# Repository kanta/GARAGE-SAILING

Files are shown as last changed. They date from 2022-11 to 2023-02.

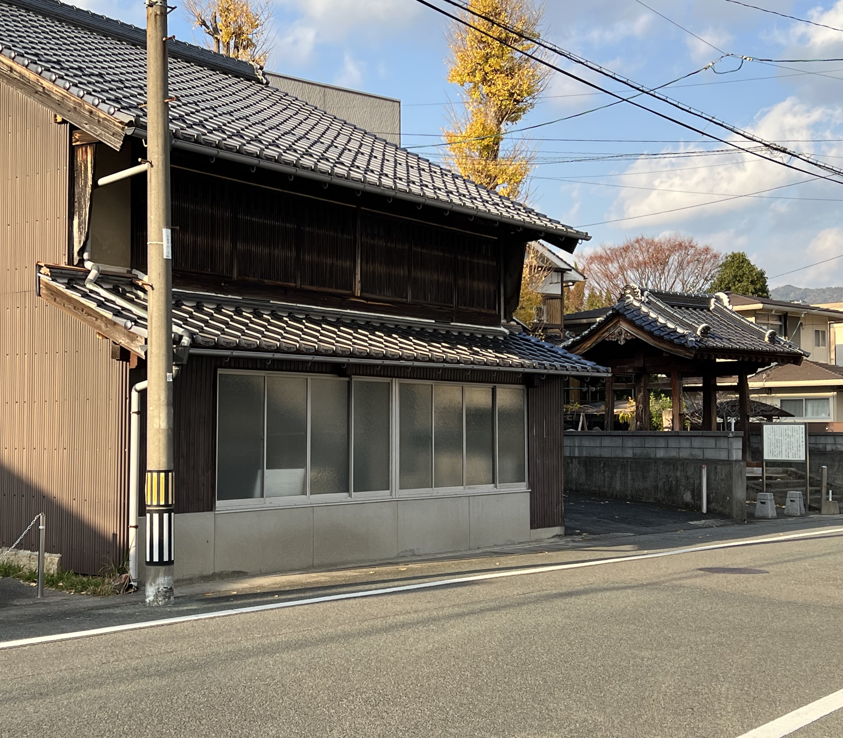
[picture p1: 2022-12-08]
Silk-screen/materials/trimmed_DaF.jpg

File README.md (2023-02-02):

# GARAGE SAILING
- [English](./README_en.md)
- [GARAGE SAILING FMラジオ](https://github.com/kanta/GARAGE-SAILING/tree/main/GarageSailing-FM-radio)

<Strong>梅田哲也 / ジョン・リチャーズ (Dirty Electronics) / ティム・ショウ / 堀尾寛太 </strong>
<a href="https://github.com/kanta/GARAGE-SAILING/blob/main/GarageSailing_Flyer.pdf">garage_sailing_flyer</a>

今冬、サウンド・アーティストのジョン・リチャーズ、ティム・ショウが来日します。2人はそれぞれ楽器や道具をDIYで製作し、UKを拠点に国際的に活躍しています。

Do a Front はもともと二人と交流がある日本のアーティスト・梅田哲也（大阪）と堀尾寛太（東京）を同時に招聘し、4人の滞在制作の成果公演として、日没のマジックアワーにガレージセールとセーリング（航海）をモチーフにした展覧会を開催します。

場内ではアーティストたちがそれぞれの作品テーマに基づいたショップを一時的にオープンし、観客はFMラジオをつかって、アーティストたちが発信する音を受信しながら会場内を移動していきます。ショップで制作した作品はその場で購入することもできます。

国際的に活躍する4人のワールドプレミアとなる新作公演にご期待ください！

## 日時
2022年12月10日（土）<br />
15:00 開場<br />
16:00 展覧会スタート、日没まで

2022年12月11日（日）<br />
10:00 ワークショップ＆製作物展示、日没まで

## 会場
[Do a front](https://www.doafront.org/about/index.html)<br />
山口県山口市堂の前町1-9

入場無料<br />
暖かいお飲み物の販売あり

- ヘッドホンおよび、イヤホンで聞けるFMラジオをご持参ください。
- お持ちでない方には会場で貸し出ししますが、数に限りがございます（滞在制作した自作ラジオを購入することもできます）。
- 会場は寒いので暖かくしてお越しください。

主催　Do a front

## 出演者
### 梅田哲也
Umeda

建物の構造や周囲の環境から着想を得て、その場でしか成立しえない現象としての時間を演出する。これまで美術館や博物館での展覧会のほかに、劇場のパフォーマンス公演や、普段行き慣れない場所へ観客を招待するツアー型の作品を発表。近年の個展・公演には「梅田哲也 イン 別府『Ｏ滞』」（別府、2020-2021年）、「うたの起源」（福岡市美術館、福岡、2019-2020年）、「プレイタイム」（シアターコクーン、2020年）などがある。<br />
https://siranami.com/

### ジョン・リチャーズ (Dirty Electronics)
Richards

ジョン・リチャーズは90年代から音楽や舞台芸術の分野で活動するアーティスト。過去数回にわたって来日し、勅使河原三郎やメルツバウら他のアーティストたちとのコラボレーションを行ってきた。近年は大人数による電子音楽とDIY電子工作のパフォーマンスに関心を持ち、批評的な制作に焦点をあてた「ダーティー・エレクトロニクス」という概念を探求し、ワークショップ・インスタレーションやパフォーマンス・インスタレーション、執筆活動など、さまざまな方法で即興的な実線を行っている。<br />
https://www.dirtyelectronics.org/

### ティム・ショウ
Shaw

音、光、コミュニケーション・メディアを扱うアーティスト。パフォーマンス、インスタレーション、サウンドウォークなどの形で作品を発表している。フィールドレコーディング、電子工作、ビデオ、モジュラーシンセシス、サウンドオブジェクト、自作ハードウェア、DIYソフトウェアなどを用いた彼の作品、録音、文章は「The Guardian」や「BBC」を中心とした数多くの国際的なメディアで紹介されている。初来日。<br />
https://tim-shaw.net/

### 堀尾寛太
Horio

日用品や自作の装置を使って音や光、磁力、位置などのエネルギーと物理的な動きを結びつけ、その場で自律的に発生する現象を作るライブパフォーマンスやインスタレーション作品を発表している。また、エンジニアとして触覚と振動に基づく電子楽器やインタフェースの開発・製作を行っている。近年の活動・展覧会には、ボアダムズの∈Y∋を中心としたユニット「FINALBY( )」（2021年〜）や、「streaming heritage 2021 autumn」（名古屋市内、2021年）などがある。<br />
https://horiokanta.com/

## クレジット
- 藏田章子：企画
- 尾中俊介 (Calamari inc)：フライヤーデザイン
- アリ・シャリフッディン：ハーブ・薬草茶
- 時里充：映像技術、映像機材協力
- 大脇理智：音響機材・映像機材協力
- 東岳志：音響ケーブル協力

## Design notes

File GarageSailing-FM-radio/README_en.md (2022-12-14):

# GARAGE SAILING FM RADIO
[日本語](README.md)



## How to use
### 1. Power switch
When you turn the switch on, you will see a green light from the round indicator avobe the switch. This will blink once in 2 seconds.
### 2. Earphone jack
A cable of your earphone will work as an anntena as well.

### 3. Volume adjust
You can change the volume with both triangle touch switches.

### 4. Scan switch
When you push the switch, radio will scan FM stations automatically. During scanning, you will see a color from the indicator next to the switch. This colour shows the frequency of the radio. Red means low frequency and purple means high frequency, as visible light spectrum. When the radio turned the station, the scan will be stopped and the indicator will be turned off.

### 5. "Ghost Radio"
This touch switch triggers "Ghost Radio" function, which jump among frequencies random and quick, to hear the sound of ghosts.

### 6. Screws for changing batteries
You can change batteries with removing these 2 screws. This radio uses 2 UM-4 batteries.

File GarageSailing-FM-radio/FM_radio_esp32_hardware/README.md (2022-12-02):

KiCad 6.0 project files for the top and the bottom panel.

FM_radio_esp32_top

BOM list:
https://docs.google.com/spreadsheets/d/1gx5q1M0V2GI4ifzEtNZcrifsvwdLu0RDMLZBMcAdJLQ/edit?usp=sharing

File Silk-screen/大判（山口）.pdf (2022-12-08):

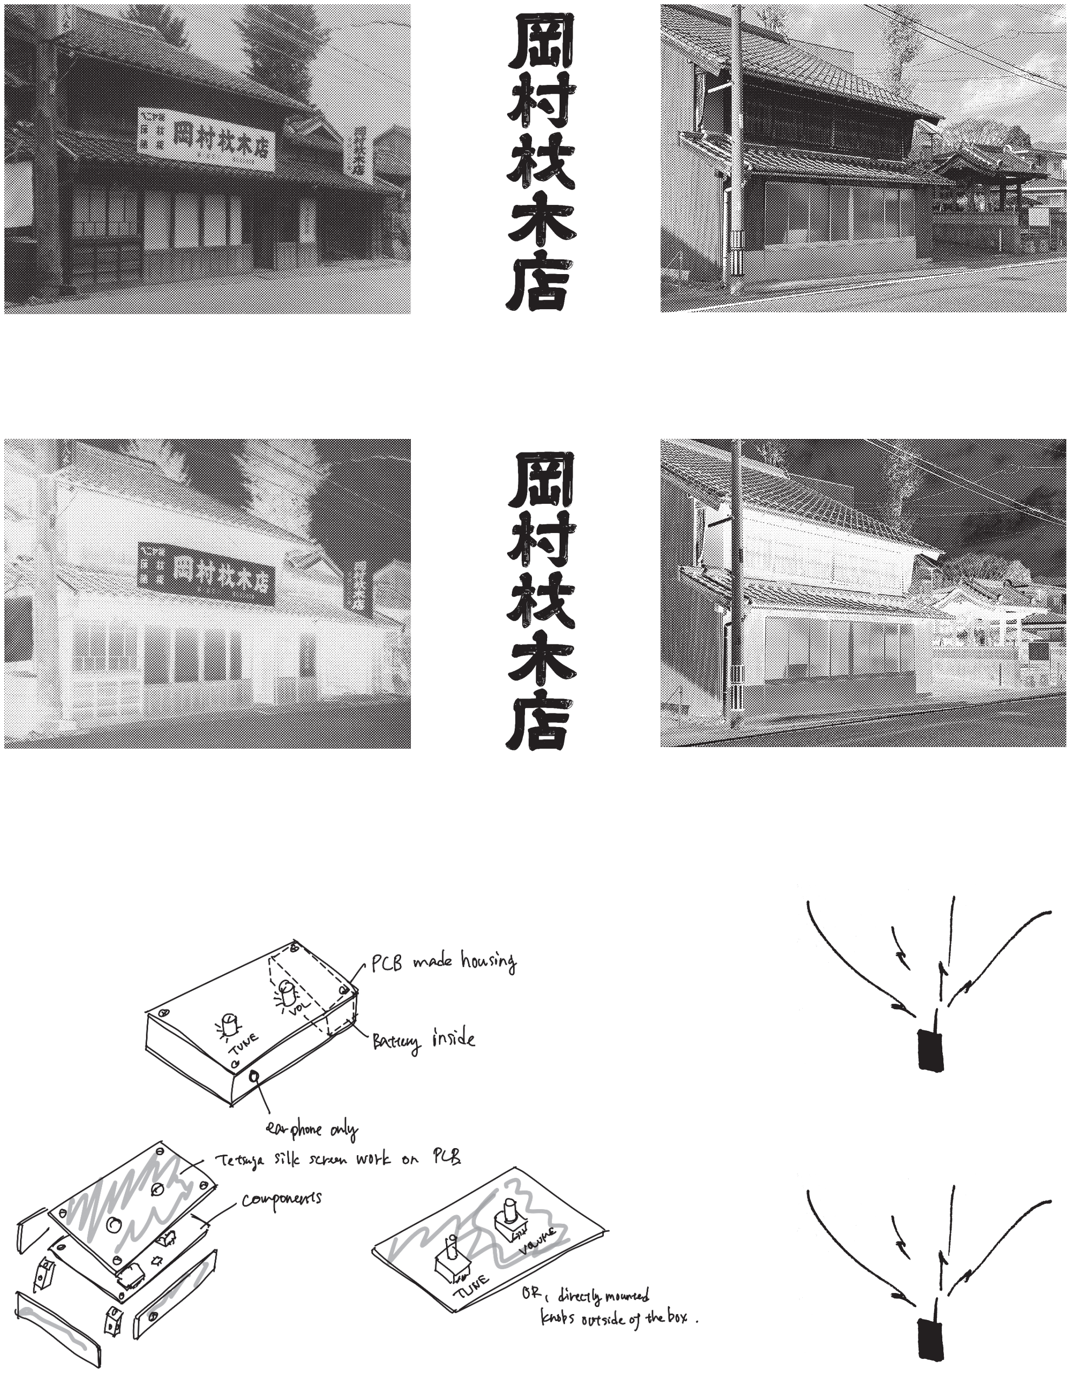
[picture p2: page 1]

１３cm | １３cm
２２cm | ８cm

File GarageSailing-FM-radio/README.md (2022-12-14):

# GARAGE SAILING FM RADIO
[English](README_en.md)



## 使い方
### 1. 電源スイッチ
電源を入れると、スイッチ上の〇部分が緑色に光ります。この緑色は2秒に1回光ります。
### 2. イヤフォンジャック
イヤフォンの線はアンテナを兼ねています。
### 3. 音量調整 
上下の三角がタッチスイッチになっていて、音量を調節できます。
### 4. スキャンスイッチ
このボタン押すと自動的に放送局をスキャンします。スキャン中は5番の位置にあるLEDが点灯し、色で周波数を表しています。光の波長に倣って、低い周波数が赤色、高い周波数が紫色です。チューニングが合うとスキャンが停止し、5番LEDが消灯します。
### 5. "Ghost Radio"
周波数を高速かつランダムにスキャンして霊の声を聴くという"Ghost Radio"の機能です。

### 6. 電池交換時に取り外すねじ
電池は単4電池2本です。音が鳴らなくなったら、この2つのねじを外して電池ボックスを取り出し、電池を交換してください。

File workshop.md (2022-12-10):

# GARAGE SAILING ワークショップ: RADICAL “WOOD” CHIP


## 日時：
2022年12月11日（日）10:30-13:00

## 会場：
Do a front

## 参加費
2500円（材料費含む）

## 定員：
6名まで

## 説明：
Dirty Electronicsのアットホームなワークショップに参加しませんか？<br />
電子部品の材料シリコンチップとウッドチップ、そして釘が出会う元材木店で、自分だけのRadical 'Wood' Chip シンセサイザーを作りましょう。<br />
このワークショップでは、木と釘と電子部品で回路を作って、自分だけのオブジェを作ります。年齢や予備知識、能力を問わずご参加いただけます。工具や材料はこちらでご提供します。<br />

https://github.com/kanta/GARAGE-SAILING
https://dirtyelectronics.org

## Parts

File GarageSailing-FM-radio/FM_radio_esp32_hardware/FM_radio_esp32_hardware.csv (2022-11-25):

Cmp name | Value | Footprint | Ref | Qty | Description
C | 0.1uF | Capacitor_SMD:C_0603_1608Metric | C1, C6 | 2 | Unpolarized capacitor
C | 1u | Capacitor_SMD:C_0603_1608Metric | C2 | 1 | Unpolarized capacitor
C | 10uF | Capacitor_SMD:C_0805_2012Metric | C3, C4 | 2 | Unpolarized capacitor
C | 47uF | Capacitor_SMD:C_1210_3225Metric | C5 | 1 | Unpolarized capacitor
C | 1nF | Capacitor_SMD:C_0603_1608Metric | C7 | 1 | Unpolarized capacitor
LED | LED | FM_radio_esp32:LED_D3.0mm | D1 | 1 | Light emitting diode
LED_RGBK | LED_RGBK | LED_THT:LED_D5.0mm-4_RGB_Wide_Pins | D3 | 1 | RGB LED, red/green/blue/cathode
D_Zener | D_Zener | Diode_SMD:D_SOD-323 | D4 | 1 | Zener diode
MountingHole_Pad | MountingHole_Pad | TestPoint:TestPoint_Keystone_5019_Minature | H1 | 1 | Mounting Hole with connection
MountingHole_Pad | MountingHole_Pad | MountingHole:MountingHole_3.2mm_M3_Pad | H2, H3, H4, H5 | 4 | Mounting Hole with connection
MountingHole | MountingHole | MountingHole:MountingHole_3.2mm_M3 | H6, H7, H8, H9 | 4 | Mounting Hole without connection
MountingHole | MountingHole | FM_radio_esp32:Hole_8mm | H10 | 1 | Mounting Hole without connection
MountingHole | MountingHole | MountingHole:MountingHole_6.5mm | H11 | 1 | Mounting Hole without connection
AudioJack2_Ground_SwitchT | AudioJack2_Ground_SwitchT | FM_radio_esp32:Jack_3.5mm_RS_913-1055 | J1 | 1 | Audio Jack, 2 Poles (Mono / TS), Grounded Sleeve, Switched T Pole (Normalling)
Conn_01x06 | Conn_01x06 | Connector_PinHeader_2.54mm:PinHeader_1x06_P2.54mm_Vertical_SMD_Pin1Left | J2 | 1 | Generic connector, single row, 01x06, script generated (kicad-library-utils/schlib/autogen/connector/)
Conn_02x03_Odd_Even | Conn_02x03_Odd_Even | Connector_PinHeader_2.54mm:PinHeader_2x03_P2.54mm_Vertical_SMD | J3 | 1 | Generic connector, double row, 02x03, odd/even pin numbering scheme (row 1 odd numbers, row 2 even numbers), script generated (kicad-library-utils/schlib/autogen/connector/)
Conn_02x03_Odd_Even | Conn_02x03_Odd_Even | Connector_PinSocket_2.54mm:PinSocket_2x03_P2.54mm_Vertical_SMD | J4 | 1 | Generic connector, double row, 02x03, odd/even pin numbering scheme (row 1 odd numbers, row 2 even numbers), script generated (kicad-library-utils/schlib/autogen/connector/)
R | 10k | Resistor_SMD:R_0603_1608Metric | R1, R2, R3 | 3 | Resistor
R | 1k | Resistor_SMD:R_0603_1608Metric | R4, R8 | 2 | Resistor
R | 330 | Resistor_SMD:R_0603_1608Metric | R6, R7 | 2 | Resistor
SW_Push | SW_Push | Button_Switch_SMD:SW_SPST_SKQG_WithoutStem | SW1 | 1 | Push button switch, generic, two pins
SW_SPDT | SW_SPDT | FM_radio_esp32:Toggle_Sw_1MS1-T1-B1-M1-Q-N | SW2 | 1 | Switch, single pole double throw
SW_SPST | SW_SPST | Button_Switch_THT:SW_PUSH-12mm | SW3 | 1 | Single Pole Single Throw (SPST) switch
TestPoint | TestPoint | TestPoint:TestPoint_Keystone_5019_Minature | TP1, TP2 | 2 | test point
ESP32-WROOM-32D | ESP32-WROOM-32D | RF_Module:ESP32-WROOM-32 | U1 | 1 | RF Module, ESP32-D0WD SoC, Wi-Fi 802.11b/g/n, Bluetooth, BLE, 32-bit, 2.7-3.6V, onboard antenna, SMD
RDA5807 | RDA5807 | FM_radio_esp32:RDA5807H | U2 | 1

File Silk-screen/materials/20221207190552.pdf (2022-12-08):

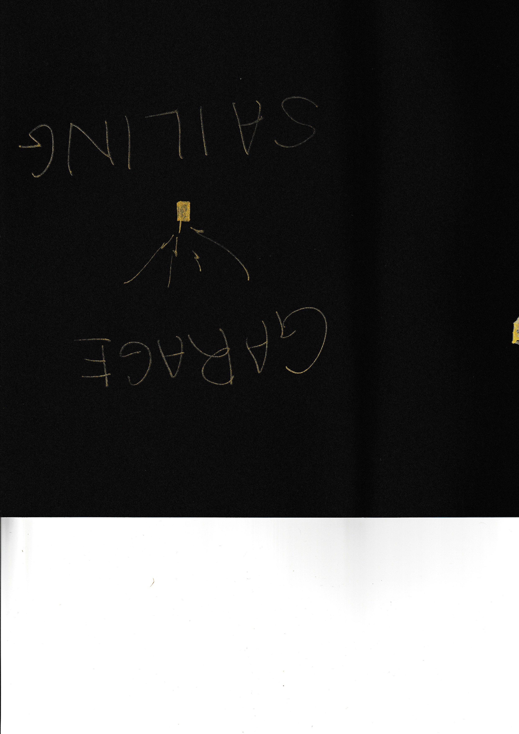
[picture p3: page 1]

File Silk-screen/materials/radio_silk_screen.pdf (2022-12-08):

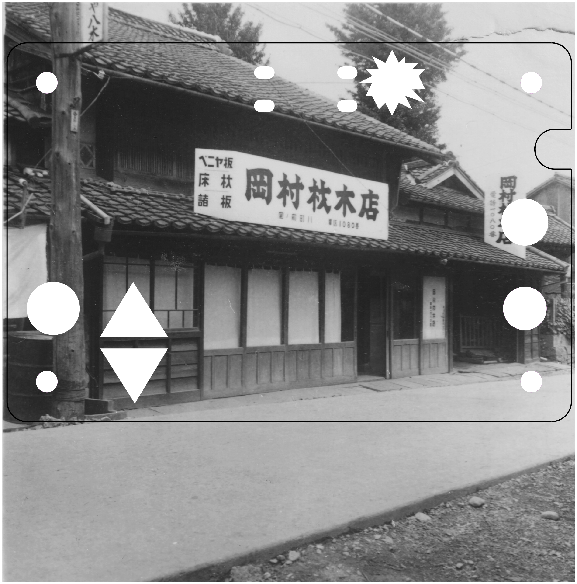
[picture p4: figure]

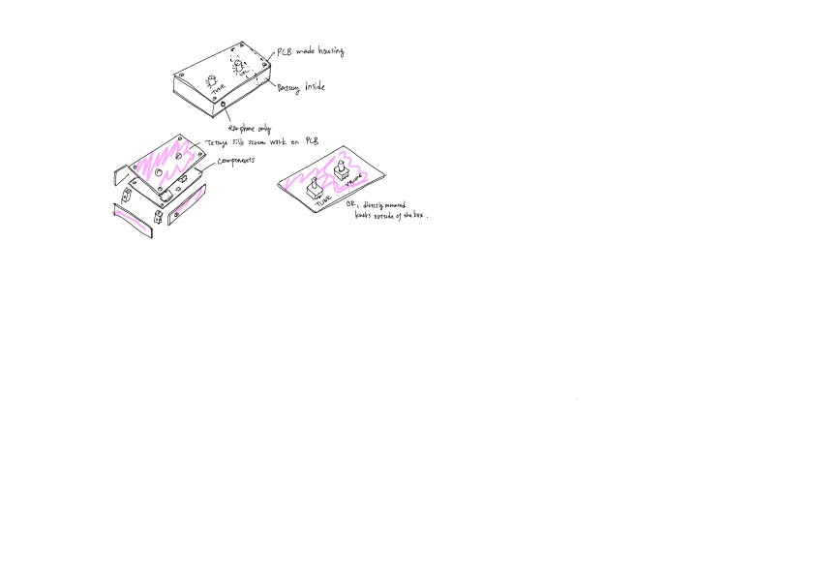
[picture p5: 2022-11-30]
Silk-screen/materials/radio_drawing.png

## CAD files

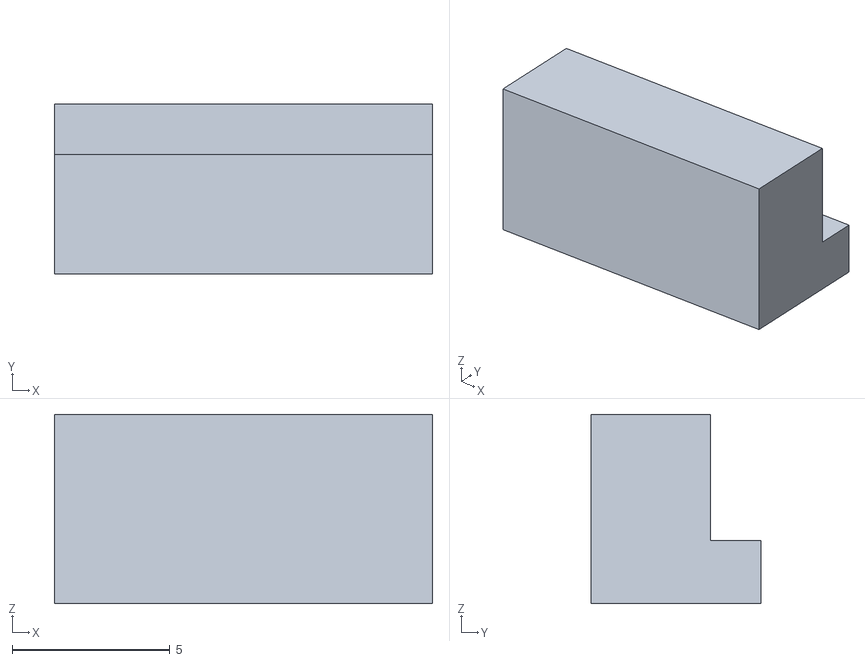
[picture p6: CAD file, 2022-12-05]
GarageSailing-FM-radio/case/5mmLED_jig.stl
12.0 x 5.40 x 6.00

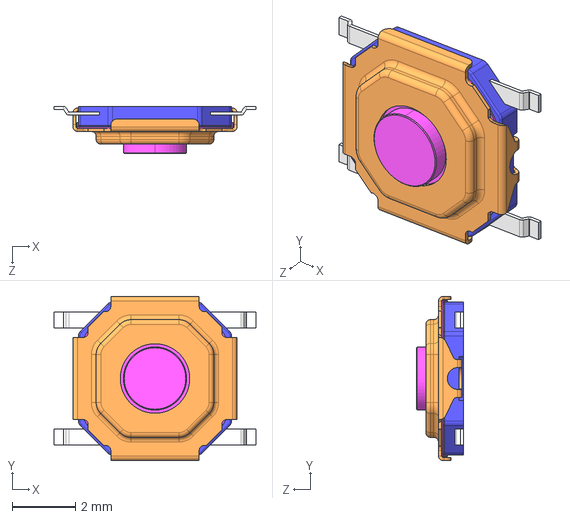
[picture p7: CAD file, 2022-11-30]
GarageSailing-FM-radio/FM_radio_esp32_hardware/local_libraries/SKQGAB.STEP
6.40 x 5.20 x 1.50 mm

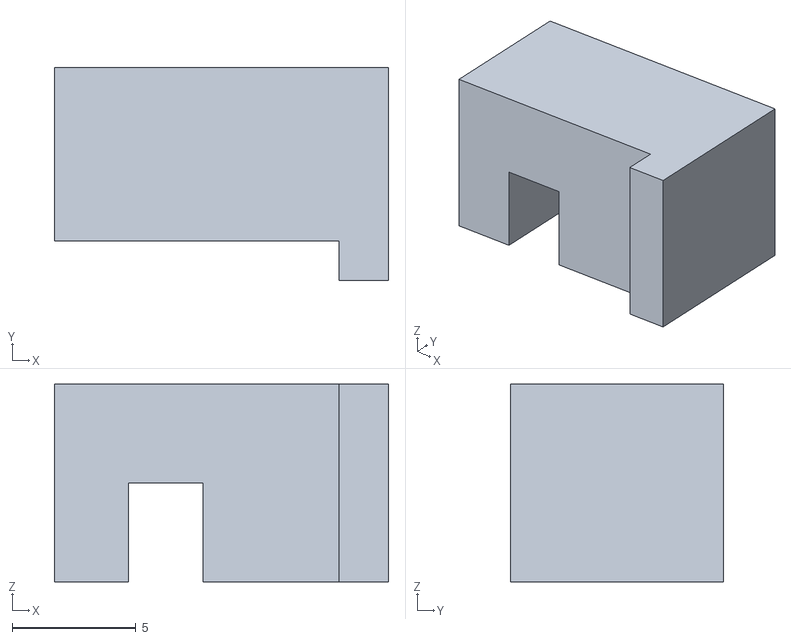
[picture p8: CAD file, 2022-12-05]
GarageSailing-FM-radio/case/3mmLED_jig.stl
13.5 x 8.60 x 8.00

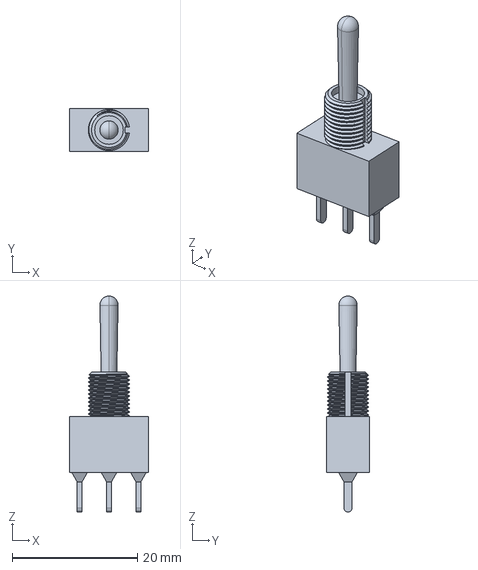
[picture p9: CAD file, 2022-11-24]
GarageSailing-FM-radio/FM_radio_esp32_hardware/local_libraries/c-3-1825136-8-a-3d.stp
12.7 x 6.86 x 34.5 mm

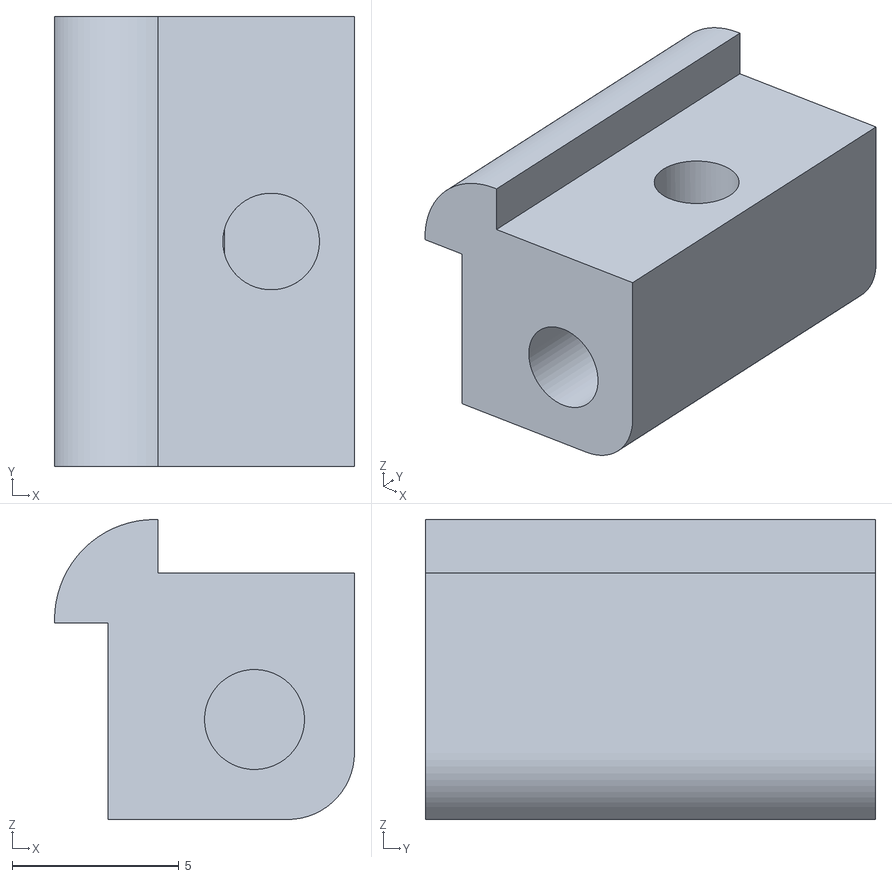
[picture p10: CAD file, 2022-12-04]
GarageSailing-FM-radio/case/case_corner_v4.stl
9.00 x 13.5 x 9.00

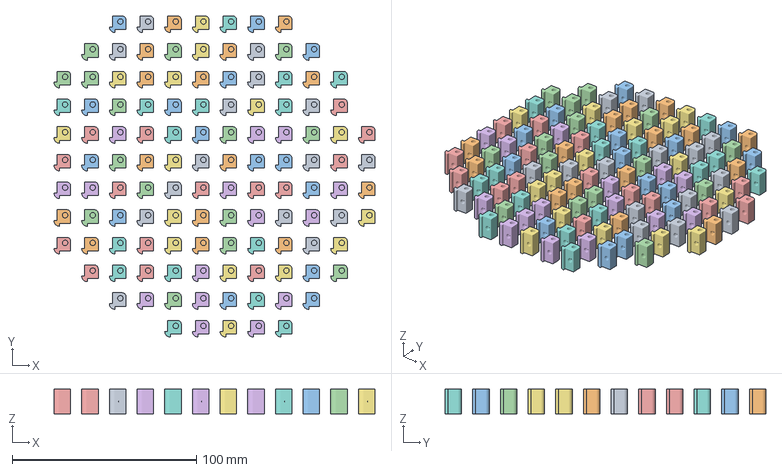
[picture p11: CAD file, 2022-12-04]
GarageSailing-FM-radio/case/case_corner_v4_120pcs.3mf
174.0 x 174.0 x 13.5 mm
case_corner_v4.stl x 120

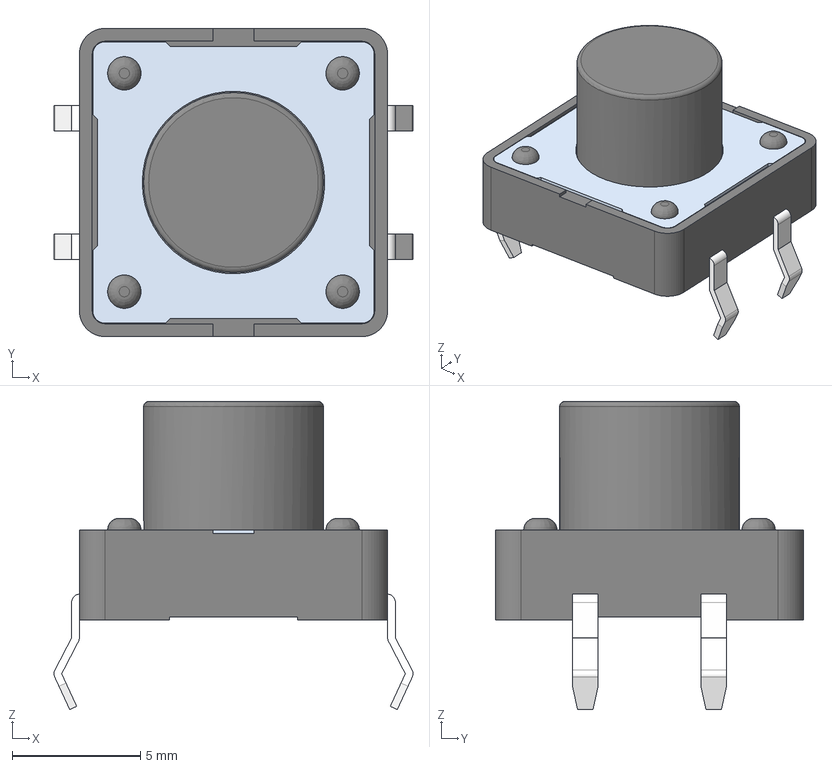
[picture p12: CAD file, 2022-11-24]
GarageSailing-FM-radio/FM_radio_esp32_hardware/local_libraries/430476085716_rev1.stp
14.0 x 12.0 x 12.0 mm

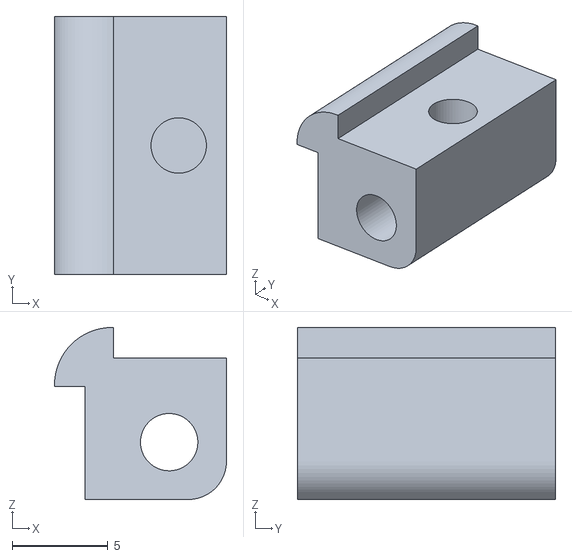
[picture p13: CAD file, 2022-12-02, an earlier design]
GarageSailing-FM-radio/case/case_corner.stl
9.00 x 13.5 x 9.00

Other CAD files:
GarageSailing-FM-radio/FM_radio_esp32_hardware/local_libraries/c-3-1825136-8-a-3d.igs

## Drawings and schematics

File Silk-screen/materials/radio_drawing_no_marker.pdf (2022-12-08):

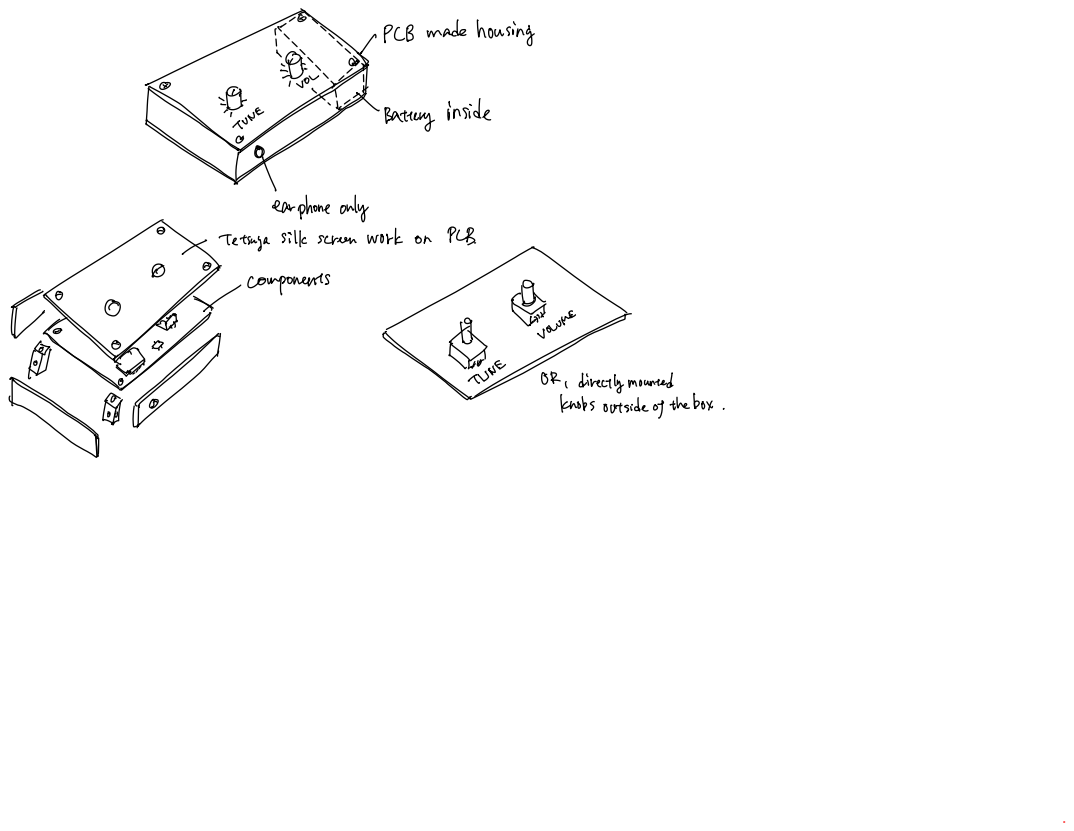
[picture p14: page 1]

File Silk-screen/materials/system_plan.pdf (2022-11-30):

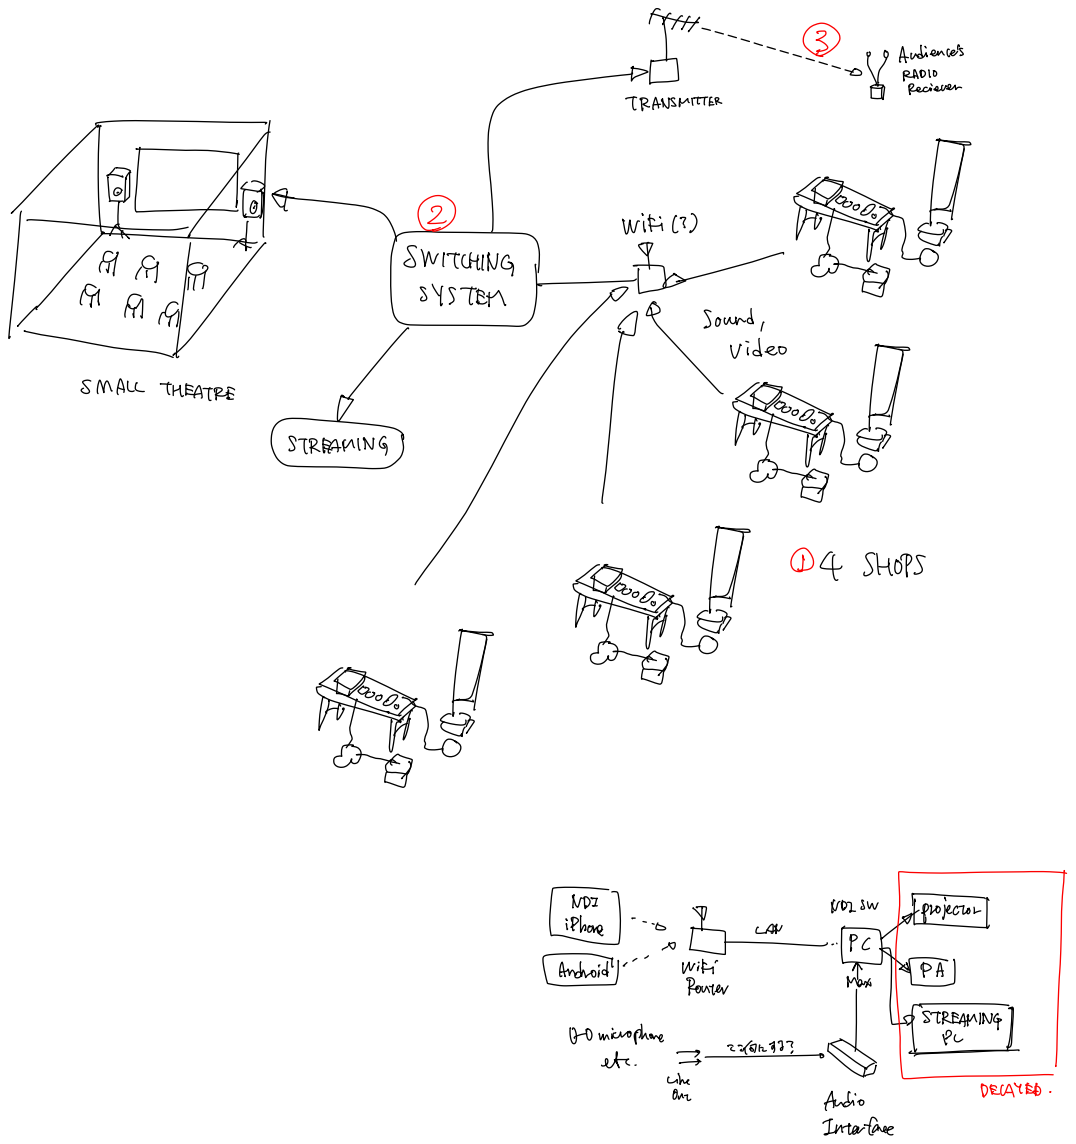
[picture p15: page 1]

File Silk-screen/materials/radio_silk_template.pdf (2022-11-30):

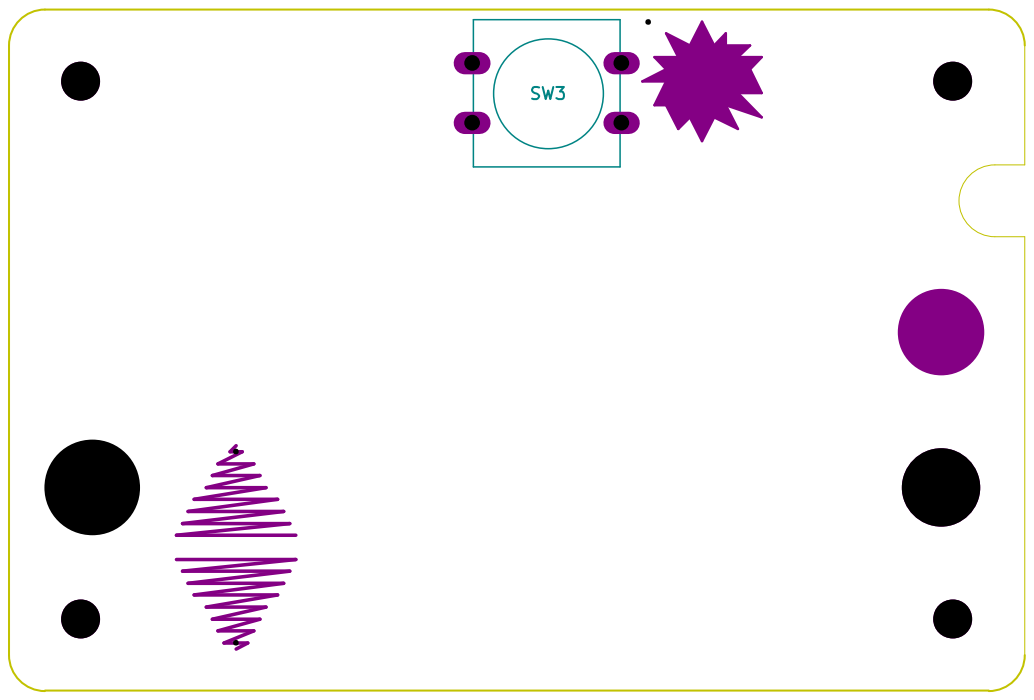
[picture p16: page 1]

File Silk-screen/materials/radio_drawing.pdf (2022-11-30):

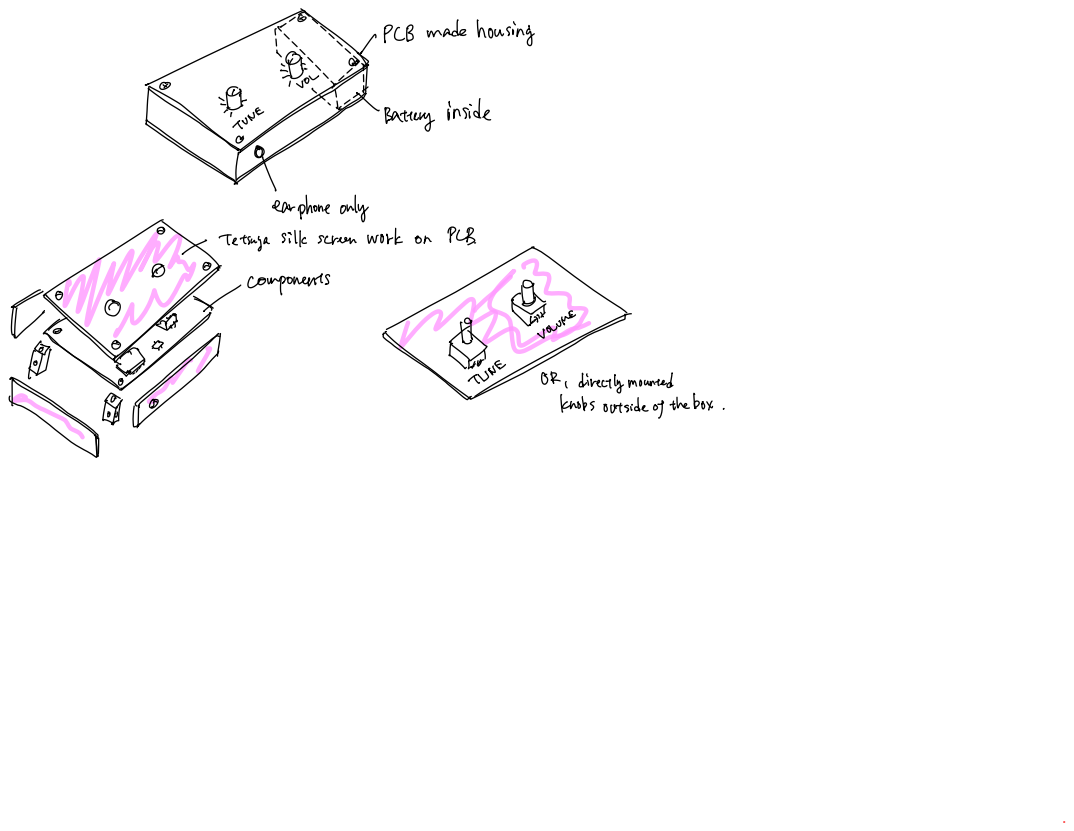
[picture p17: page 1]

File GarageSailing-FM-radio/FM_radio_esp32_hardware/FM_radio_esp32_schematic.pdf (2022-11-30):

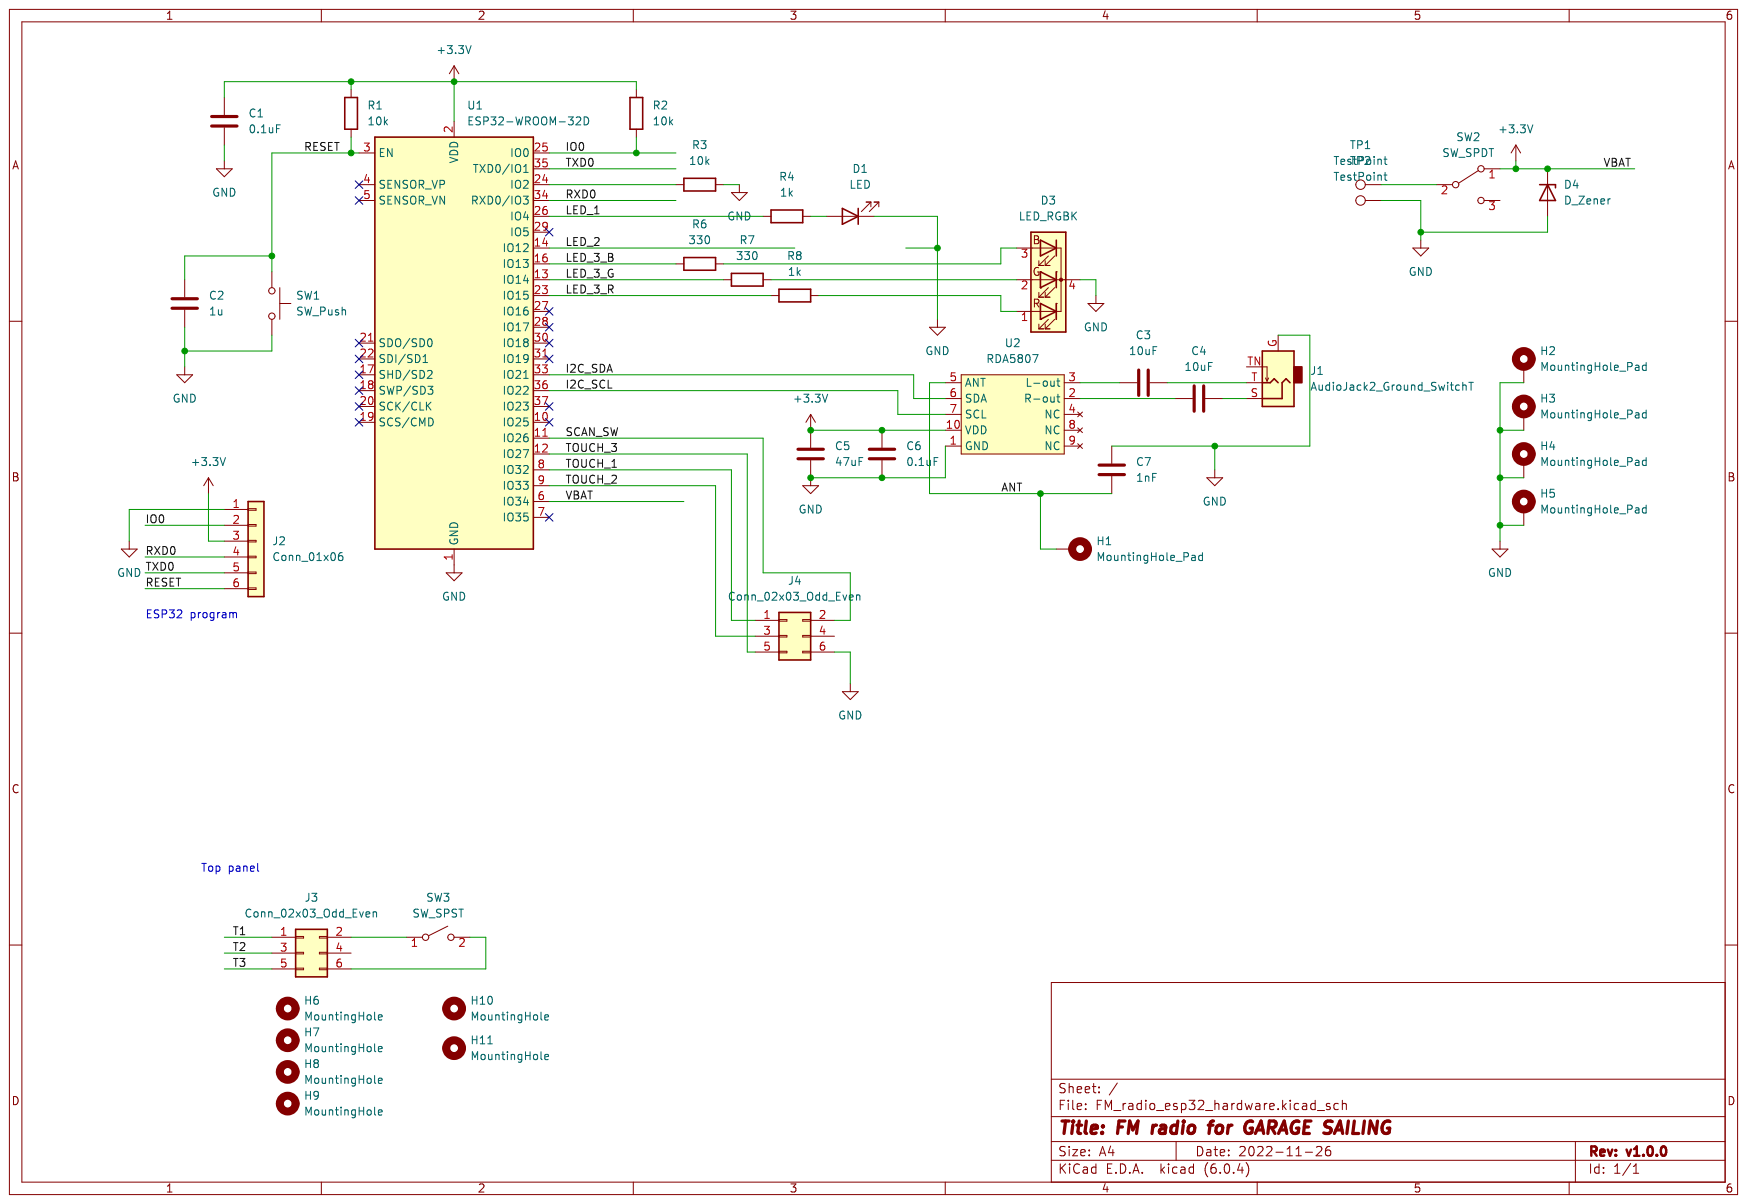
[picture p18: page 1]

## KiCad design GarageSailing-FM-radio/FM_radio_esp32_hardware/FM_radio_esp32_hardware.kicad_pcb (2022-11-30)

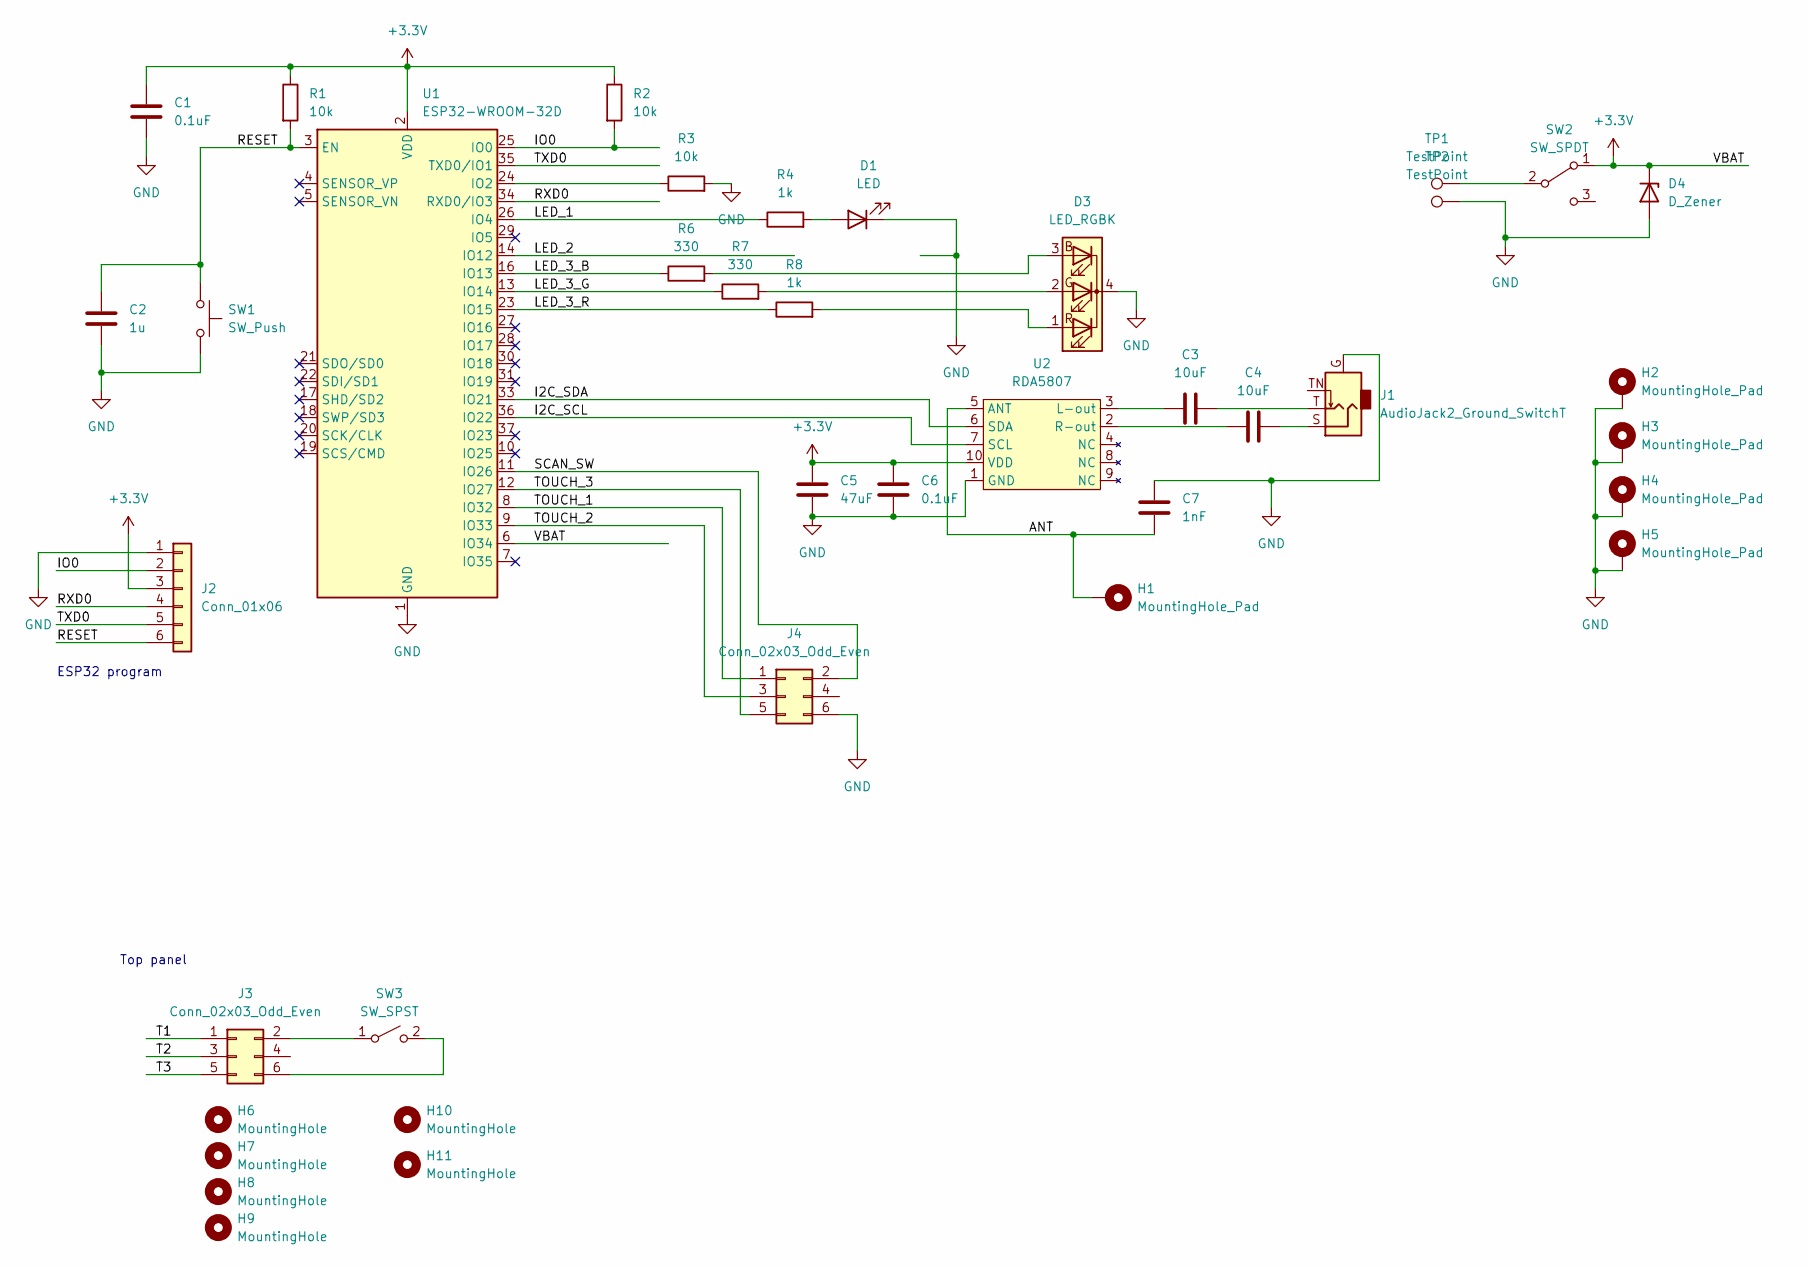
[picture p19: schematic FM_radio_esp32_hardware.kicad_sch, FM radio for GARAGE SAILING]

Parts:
C1, C6: 0.1uF; C_0603_1608Metric
C2: 1u; C_0603_1608Metric
C3, C4: 10uF; C_0805_2012Metric
C5: 47uF; C_1210_3225Metric
C7: 1nF; C_0603_1608Metric
D1: LED; LED_D3.0mm
D3: LED_RGBK; LED_D5.0mm-4_RGB_Wide_Pins
D4: D_Zener; D_SOD-323
H1: MountingHole_Pad; TestPoint_Keystone_5019_Minature
H2, H3, H4, H5: MountingHole_Pad; MountingHole_3.2mm_M3_Pad
H6, H7, H8, H9: MountingHole; MountingHole_3.2mm_M3
H10: MountingHole; Hole_8mm
H11: MountingHole; MountingHole_6.5mm
J1: AudioJack2_Ground_SwitchT; Jack_3.5mm_RS_913-1055
J2: Conn_01x06; PinHeader_1x06_P2.54mm_Vertical_SMD_Pin1Left
J3: Conn_02x03_Odd_Even; PinHeader_2x03_P2.54mm_Vertical_SMD
J4: Conn_02x03_Odd_Even; PinSocket_2x03_P2.54mm_Vertical_SMD
R1, R2, R3: 10k; R_0603_1608Metric
R4, R8: 1k; R_0603_1608Metric
R6, R7: 330; R_0603_1608Metric
SW1: SW_Push; SW_SPST_SKQG_WithoutStem
SW2: SW_SPDT; Toggle_Sw_1MS1-T1-B1-M1-Q-N
SW3: SW_SPST; SW_PUSH-12mm
TP1, TP2: TestPoint; TestPoint_Keystone_5019_Minature
U1: ESP32-WROOM-32D; ESP32-WROOM-32
U2: RDA5807; RDA5807H

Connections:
+3V3: C1.2, C5.1, C6.1, D4.1 (K), J2.3, R1.1, R2.1, SW2.1 (A), U1.2 (VDD), U1.6 (IO34), U2.10 (VDD)
/ANT: C7.2, H1.1, U2.5 (ANT)
/I2C_SCL: U1.36 (IO22), U2.7 (SCL)
/I2C_SDA: U1.33 (IO21), U2.6 (SDA)
/IO0: J2.2, R2.2, U1.25 (IO0)
/LED_1: R4.1, U1.26 (IO4)
/LED_2: U1.14 (IO12)
/LED_3_B: R6.1, U1.16 (IO13)
/LED_3_G: R7.1, U1.13 (IO14)
/LED_3_R: R8.1, U1.23 (IO15)
/RESET: C2.1, J2.6, R1.2, SW1.1, U1.3 (EN)
/RXD0: J2.4, U1.34 (RXD0/IO3)
/SCAN_SW: J4.2, U1.11 (IO26)
/T1: J3.1
/T2: J3.3
/T3: J3.5
/TOUCH_1: J4.1, U1.8 (IO32)
/TOUCH_2: J4.3, U1.9 (IO33)
/TOUCH_3: J4.5, U1.12 (IO27)
/TXD0: J2.5, U1.35 (TXD0/IO1)
GND: C1.1, C2.2, C5.2, C6.2, C7.1, D1.1 (K), D3.4 (K), D4.2 (A), H2.1, H3.1, H4.1, H5.1, J1.G, J2.1, J4.6, R3.2, SW1.2, TP2.1, U1.1 (GND), U1.15 (GND), U1.38 (GND), U1.39 (GND), U2.1 (GND)
unnamed: C3.1, U2.3 (L-out)
unnamed: C3.2, J1.T
unnamed: C4.1, U2.2 (R-out)
unnamed: C4.2, J1.S
unnamed: D1.2 (A), R4.2
unnamed: D3.1 (RA), R8.2
unnamed: D3.2 (GA), R7.2
unnamed: D3.3 (BA), R6.2
unnamed: J3.2, SW3.1 (A)
unnamed: J3.6, SW3.2 (B)
unnamed: R3.1, U1.24 (IO2)
unnamed: SW2.2 (B), TP1.1

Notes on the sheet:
ESP32 program
Top panel

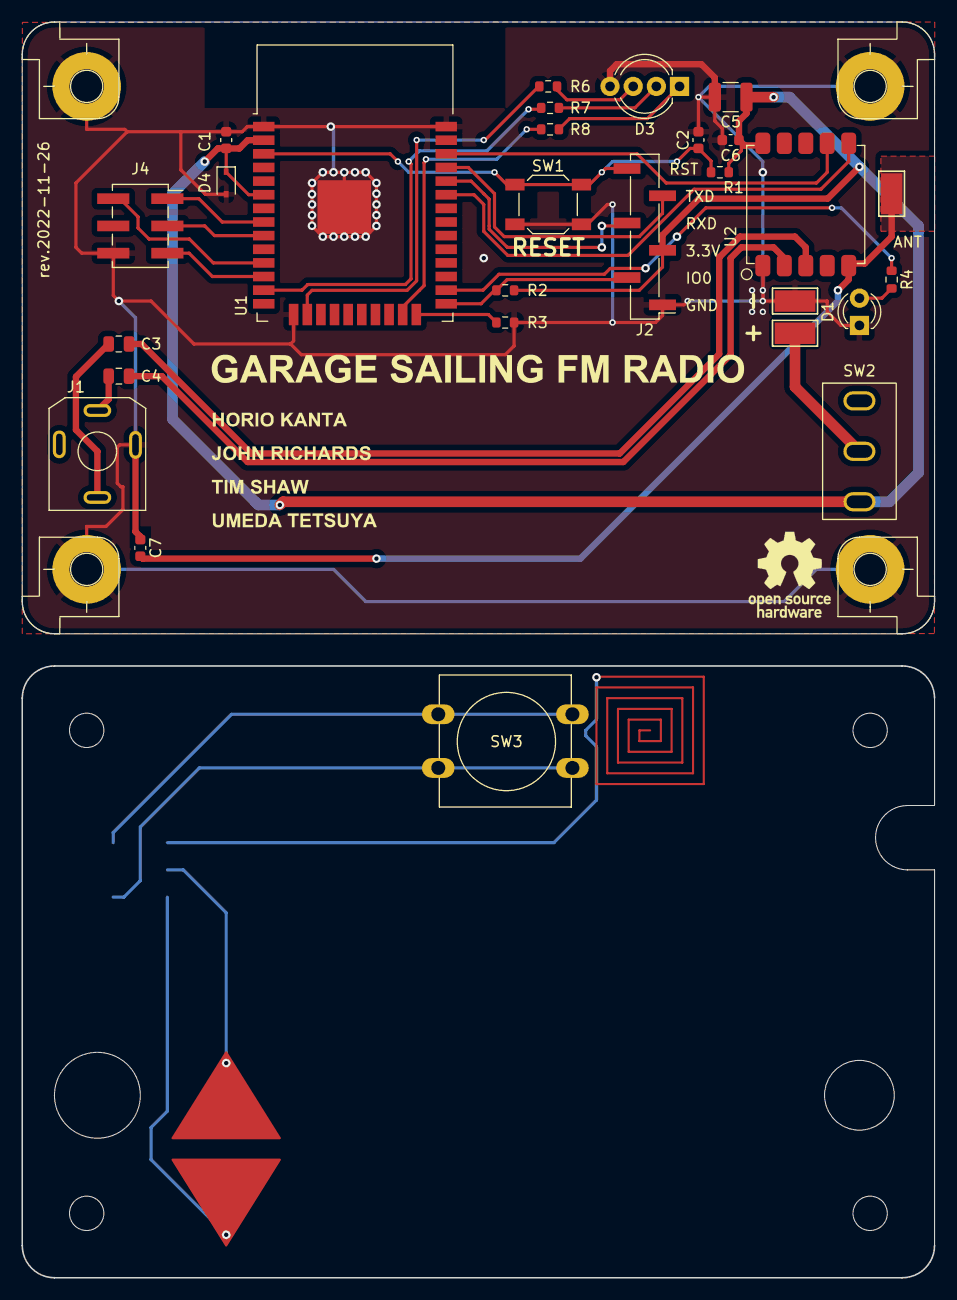
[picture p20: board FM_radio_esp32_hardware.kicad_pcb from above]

Board: 2 copper layers, 85.0 x 117.0 mm, 39 parts (1 on the bottom side), 29 nets.

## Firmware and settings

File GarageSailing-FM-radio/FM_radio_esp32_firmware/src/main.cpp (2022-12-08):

#include <Arduino.h>
#include <Wire.h>

#include <TaskManager.h>
#include <radio.h>
#include <RDA5807M.h>
// #include <RDSParser.h>

#define LED_POWER_PIN 4U
constexpr uint8_t freqLedPin[3] = {13, 15, 14}; // RGB
#define scanSwPin 26U
#define NUM_OF_TOUCH 3
constexpr uint8_t touchPin[NUM_OF_TOUCH] = {T9, T8, T7}; // 32:AUX, 33:Vol Up, 27:Vol Down

float touchBaseValue[NUM_OF_TOUCH] = {0.0};
constexpr float touchRatioThreshold[NUM_OF_TOUCH] = {0.5, 0.5, 0.5};

#define FREQ_LOW_LIMIT 7600u
#define FREQ_HIGH_LIMIT 10800U //9500U
#define DEFAULT_FREQ 8730U
uint16_t currentFreq = DEFAULT_FREQ;

RDA5807M radio; ///< Create an instance of a RDA5807 chip radio

bool lowLevelDebug = false;

void updatePowerLed()
{
  static uint16_t count = 0;
  digitalWrite(LED_POWER_PIN, (count++ < 1));
  if (count >= 120)
    count = 0;
}

void testTouchRgbLed()
{
  static uint8_t count = 0;
  digitalWrite(freqLedPin[count], LOW);
  count++;
  if (count >= 3)
    count = 0;
  Serial.printf("LED#:%d\n", count);
  digitalWrite(freqLedPin[count], HIGH);
}

void updateRgbLed(float spectrum)
{
  float r, g, b, scale;
  if (spectrum < 0.4f)
  {
    scale = spectrum * (1.0f / 0.4f);
    r = 1.0f - scale;
    g = scale;
    b = 0.0f;
  }
  else if (spectrum < 0.8f)
  {
    scale = (spectrum-0.4f) * (1.0f/0.4f);
    r = 0.0f;
    g = 1.0f - scale;
    b = scale;
  }
  else
  {
    scale = (spectrum-0.8f) * (1.0f/0.2f);
    r = scale/1.5f;
    g = 0.0f;
    b = 1.0f - (scale/2.0f);
  } 
  ledcWrite(0, r*255.0f);
  ledcWrite(1, g*100.0f);
  ledcWrite(2, b*255.0f);

}

void testRgbLed()
{
  static float phase = 0.0f;
  updateRgbLed(phase);
  phase += 0.01;
  if (phase>1.0f)
    phase = 0.0f;
}

void ghostRadio()
{
  uint16_t newFreq = (random(FREQ_LOW_LIMIT, FREQ_HIGH_LIMIT + 1) / 10) * 10;
  radio.setFrequency(newFreq);
      float s = (float)(newFreq-FREQ_LOW_LIMIT)/(float)(FREQ_HIGH_LIMIT-FREQ_LOW_LIMIT);
    updateRgbLed(s);
}

void scanSw()
{
  static bool touchState[NUM_OF_TOUCH] = {true}, swState = true;
  touch_value_t t;
  float ratio;
  int v;
  for (uint8_t i = 0; i < NUM_OF_TOUCH; i++)
  {
    ratio = (float)touchRead(touchPin[i]) / touchBaseValue[i];
    if ((ratio < touchRatioThreshold[i]) != touchState[i])
    {
      touchState[i] = !touchState[i];
      Serial.printf("Touch%d: %d\n", i, touchState[i]);
      digitalWrite(freqLedPin[i], touchState[i]);
      switch (i)
      {
      case 0:
        if (touchState[0])
        {
          Tasks["GhostRadio"]->startIntervalMsec(200);
        }
        else
        {
          Tasks["GhostRadio"]->stop();
        }
        break;
      case 1:
        if (touchState[1])
        {
          // increase volume
          v = radio.getVolume();
          if (v < 15)
            radio.setVolume(++v);
        }
        break;
      case 2:
        if (touchState[2])
        {
          v = radio.getVolume();
          if (v > 0)
            radio.setVolume(--v);
        }
        break;
      default:
        break;
      }
    }
  }
  if (digitalRead(scanSwPin) != swState)
  {
    swState = !swState;
    if (swState)
    {
      Serial.println("Seek Up.");
      radio.seekUp(true);
    }
  }
}


void updateRadioFreq()
{
  static uint16_t freq = 0;
  uint16_t t = radio.getFrequency();
  if (t != freq)
  {
    float realf = (float)t / 100.0f;
    Serial.printf("Frequency:%.1fMHz\n", realf);
    freq = t;
    float s = (float)(t-FREQ_LOW_LIMIT)/(float)(FREQ_HIGH_LIMIT-FREQ_LOW_LIMIT);
    updateRgbLed(s);
  }
  else
  {
    ledcWrite(0, 0);
    ledcWrite(1, 0);
    ledcWrite(2, 0);
  }
}

void setup()
{
  uint8_t i;
  // open the Serial port
  Serial.begin(115200);
  pinMode(RX, INPUT_PULLUP);
  Serial.print("Radio...");
  pinMode(scanSwPin, INPUT_PULLUP);
  pinMode(LED_POWER_PIN, OUTPUT);
  digitalWrite(LED_POWER_PIN, HIGH);
  for (i = 0; i < 3; i++)
  {
    // pinMode(freqLedPin[i], OUTPUT);
    ledcSetup(i, 12800, 8); 
    ledcAttachPin(freqLedPin[i], i);
  }
  for (i = 0; i < NUM_OF_TOUCH; i++)
  {
    touchBaseValue[i] = touchRead(touchPin[i]);
  }

  delay(500);

  // Enable information to the Serial port
  radio.debugEnable(true);
  radio._wireDebug(lowLevelDebug);

  // Initialize the Radio
  radio.init();

  radio.setBandFrequency(RADIO_BAND_FMWORLD, DEFAULT_FREQ);

  // delay(100);
  radio.setMono(false);
  radio.setMute(false);
  radio.setVolume(3);

  Tasks.add([]
            { scanSw(); })
      ->startIntervalMsec(30);

  Tasks.add([]
            { updateRadioFreq(); })
      ->startIntervalMsec(400);

  // LED: power on indicator
  Tasks.add([]
            { updatePowerLed(); })
      ->startIntervalFromMsec(30, 2000);

  // Ghost Radio
  Tasks.add("GhostRadio", []
            { ghostRadio(); });

  // Tasks.add([]
  //           { testRgbLed(); })
  //     ->startIntervalMsec(40);
} // Setup

void loop()
{
  Tasks.update();

  if (Serial.available()>0)
  {
    uint8_t inByte = Serial.read();
    switch (inByte)
    {
    case 's':
      radio.seekUp(true);
      break;
    
    default:
      break;
    }
  }
}

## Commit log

2022-11-20 Test pu2clr library
    [FM_radio_esp32_hardware.kicad_pcb, FM_radio_esp32_hardware.kicad_sch]
2022-11-21 a schematic update
    [FM_radio_esp32_hardware.kicad_sch]
2022-11-23 Schematic updates
    [FM_radio_esp32_hardware.kicad_pcb, FM_radio_esp32_hardware.kicad_sch]
2022-11-24 added, side panel project. dimensions are need to be fixed
    [430476085716_rev1.stp, FM_radio_esp32_hardware.kicad_pcb, FM_radio_esp32_hardware.kicad_sch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]
2022-11-25 side panels dimension update
    [FM_radio_esp32_hardware_sidepanels.kicad_pcb]
2022-11-25 minor improvements
    [FM_radio_esp32_hardware.csv, FM_radio_esp32_hardware.kicad_pcb, FM_radio_esp32_hardware.kicad_sch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]
2022-11-26 fix a too big silk pattern
    [FM_radio_esp32_hardware.kicad_pcb]
2022-11-26 new panelized data for side panels,
    [FM_radio_esp32_hardware_sidepanels.kicad_pcb]
2022-11-30 firmware simplified
    [FM_radio_esp32_hardware.kicad_pcb, SKQGAB.STEP]
2022-11-30 Organize directories
    [430476085716_rev1.stp, FM_radio_esp32_hardware.csv, FM_radio_esp32_hardware.kicad_pcb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]
2022-12-02 Changed resistors value for the RGB LED.
    [FM_radio_esp32_hardware.kicad_sch, case_corner.stl]
2022-12-04 LED soldering jigs, corner post for the housing
    [3mmLED_jig.stl, 5mmLED_jig.stl, case_corner_v4.stl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]
2022-12-04 RGB led pin arrangements hacks
    [FM_radio_esp32_hardware.kicad_sch]
2022-12-05 色味調整
2022-12-05 Update sodering jigs
    [3mmLED_jig.stl, 5mmLED_jig.stl]
2022-12-06 ghost radio, LED spectrum freq indicator etc
